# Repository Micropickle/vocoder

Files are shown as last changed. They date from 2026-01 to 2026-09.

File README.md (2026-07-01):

# THE VOCODER

a voice amplifier for use with encumbersome masks such as gas masks

## breif description
the vocoder is a device that allows you to alter your voice to your specifications and allows you to amplify it through speakers and bone transducer speakers and is especially useful in situations where wearing a mask can muffle your voice.

## inspiration
the project was first inspired by a fictonal story/world called degenesis where people called chroniclers disguised their voices using vocoders, long tubes went down their throats to gather their voice and was fed into the 'vocoder' which then was distorted and was amplifiable. along with that i own masks and gasmasks that make it hard to communicate with others so the device is meant to gather your voice via a mic or throat mic and output it via speakers or bone transducer speakers placed on the mask itself which is very useful for hobbies such as airsofting or cosplaying. the device also has professional use cases such as when having to wear heavy clothing and gasmasks such as PPE, this device will make you clearly audible to others when working

## gallery

CAD designs
`photos/CAD designs/KiCad`

initial prototype photos
`photos/prototype version`

## how to use
1. plug in mic of your choice (the standard is the audio jack port found in phones, but the board can be modified for different ports) and wire in an external speaker that meets the specifications of the amplifier chip
2. compile the project on Platformio and flash to the board (this is necessary as in the future i will implement configurations for BLE and initial settings for audio modification such as amplification, distortion, pitch changing, etc.)
3. wire in audio output of your choosing

## bill of materials

`hardware/production/bom.csv`

## initial prototype
it started off as a proof of concept through a prototype board using a simple XIAO esp32 c3 to test the idea and the limitations, this taught me alot digital audio, sound systems and BLE as all three are very necessary for this project
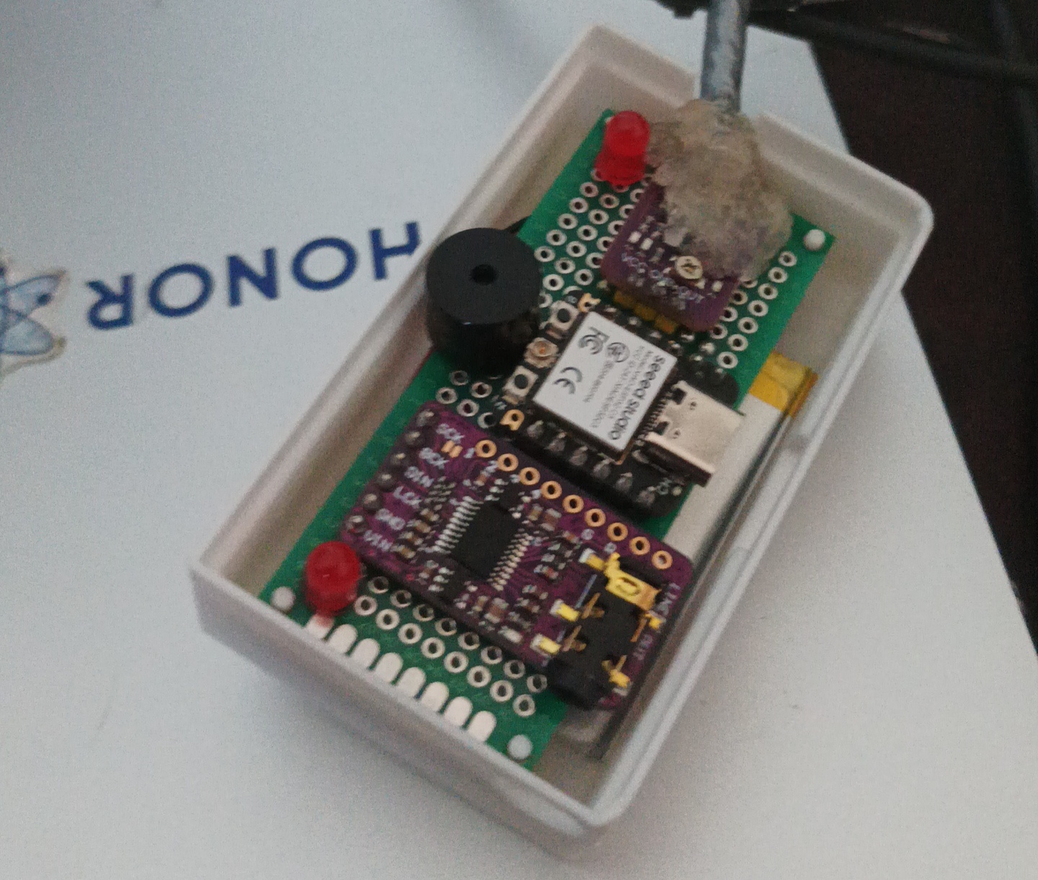
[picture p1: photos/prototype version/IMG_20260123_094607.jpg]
prototype board


the issue was everything was powered by the 3v3 pin on the esp, i had to rely on an external amplifier (and external power supply) to make it work, furthermore the esp's clock speed was too slow and brought about glitches in the audio output. 

## description
the circuit board went through many design stages primarily due to three things, errors, expense and having to include extra components to make the circuit work properly.

the main parts of the circuit are as followed
* the esp32-s3 board was chosen for its high clockspeed, familiarity and extensive functionality, the esp32-s3 WROOM board had included wifi, bluetooth, BLE and usb pins reducing external circuits needed and opening up options in terms of customisation
* the ADAU1761 is a codec that includes a ADC, DAC and built in processor to make changes to the incoming and outcoming audio, this was chosen due to its specialty in audio processing which will reduce the processing power from the esp32 and its ease of programming due to the manufacturers having dedicated graphical software for the chip, the only problem is custom drivers need to be written for the esp32 to upload the code for the ADAU1761
* the MAX98357A was chosen due to its bilt in i2s interfacw which is compatable with the esp32 and the adau1761 as both can be interfaced with the i2s bus, an amplifier was included so that the audio output can be directed to a speaker or bone transucer without an external amplifier or power supply

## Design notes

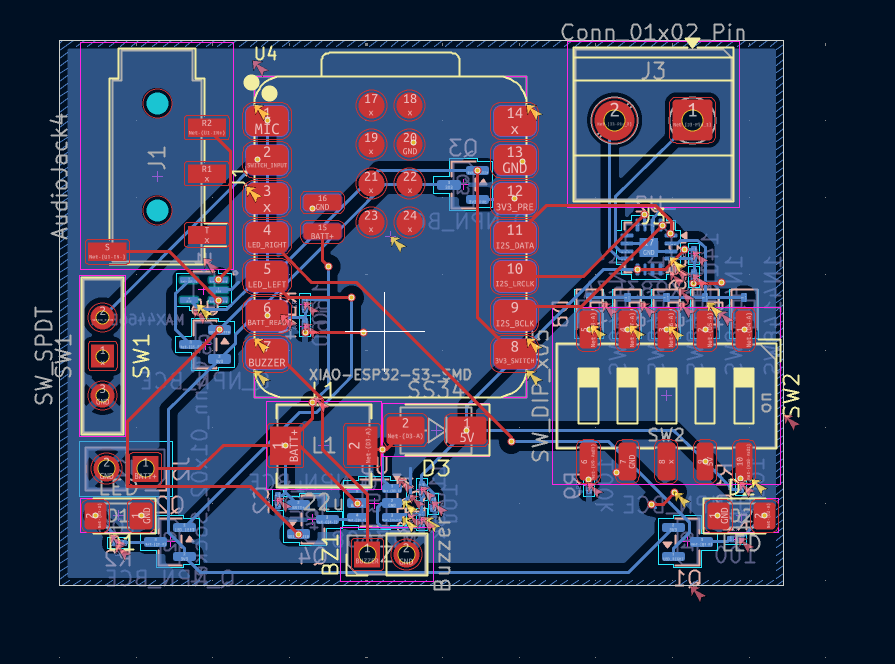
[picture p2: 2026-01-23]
photos/CAD designs/KiCad/Screenshot from 2026-01-22 20-45-09.png

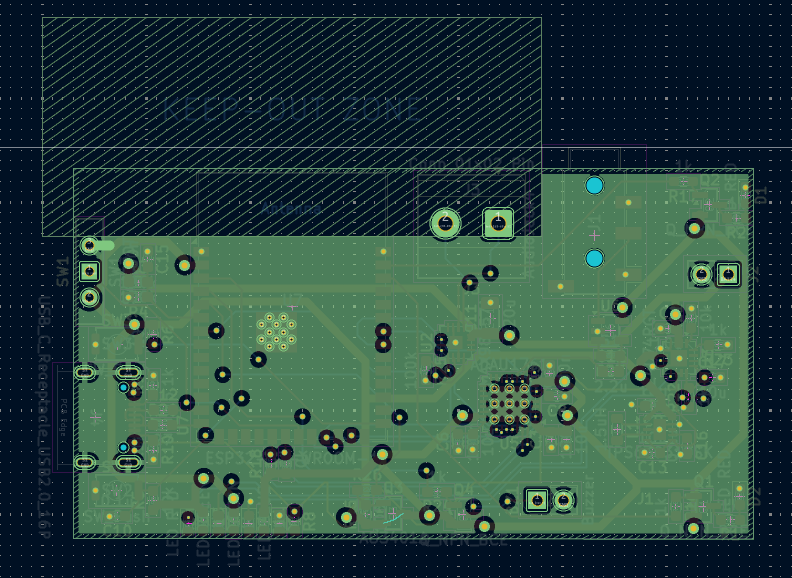
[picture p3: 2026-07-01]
photos/CAD designs/KiCad/Screenshot from 2026-07-01 14-13-31.png

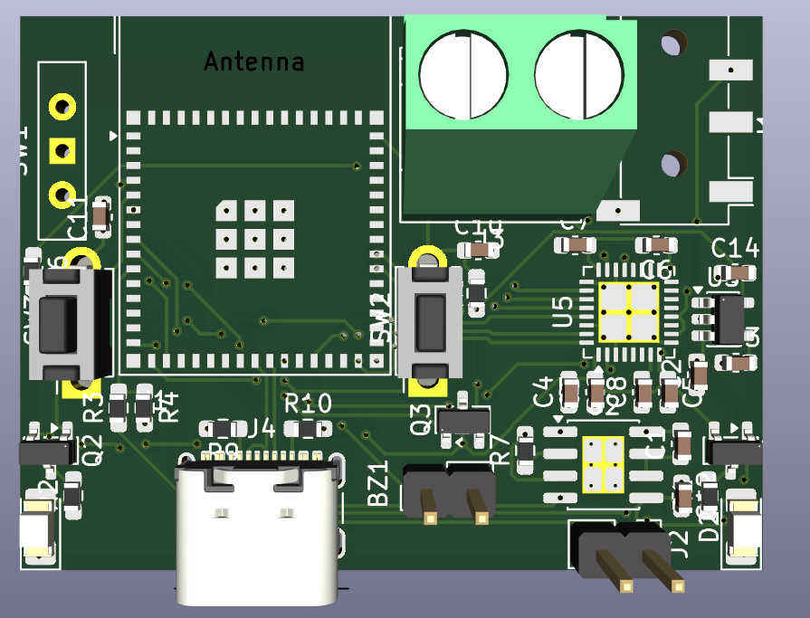
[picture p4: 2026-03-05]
photos/CAD designs/KiCad/Screenshot from 2026-03-05 19-23-45.png

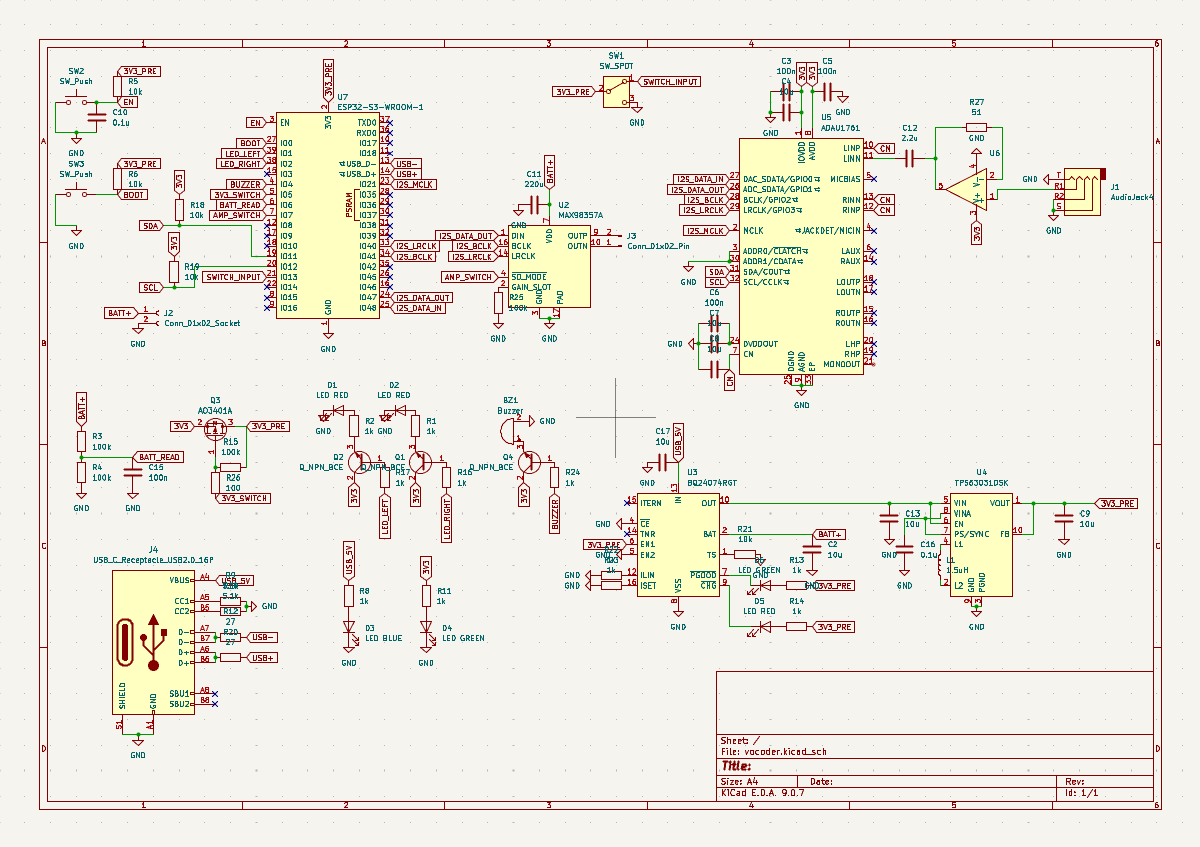
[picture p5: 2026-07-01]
photos/CAD designs/KiCad/Screenshot from 2026-07-01 14-12-51.png

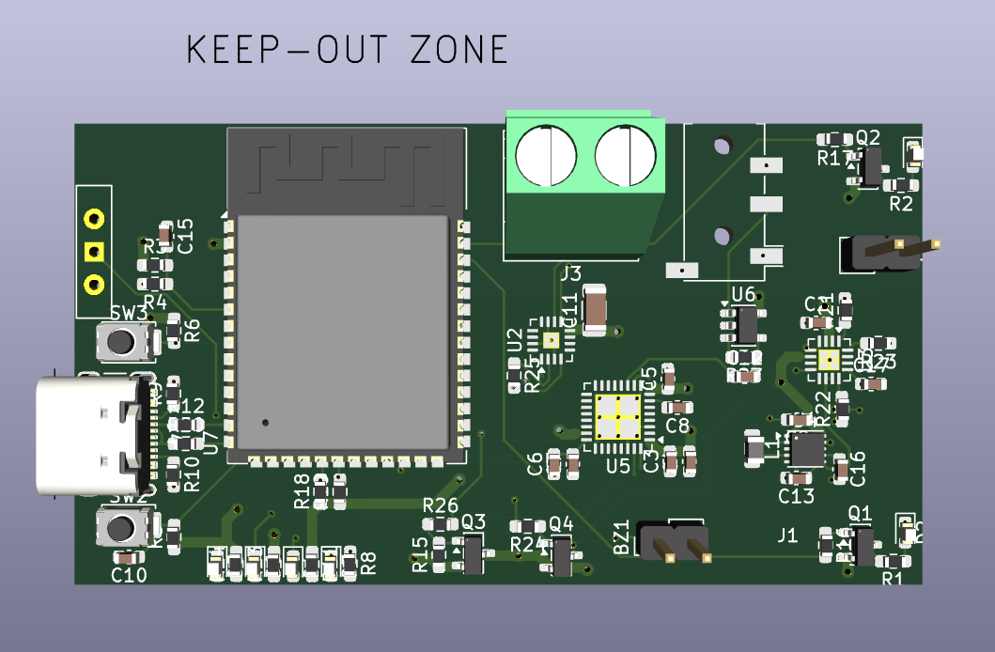
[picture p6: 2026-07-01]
photos/CAD designs/KiCad/Screenshot from 2026-07-01 14-14-14.png

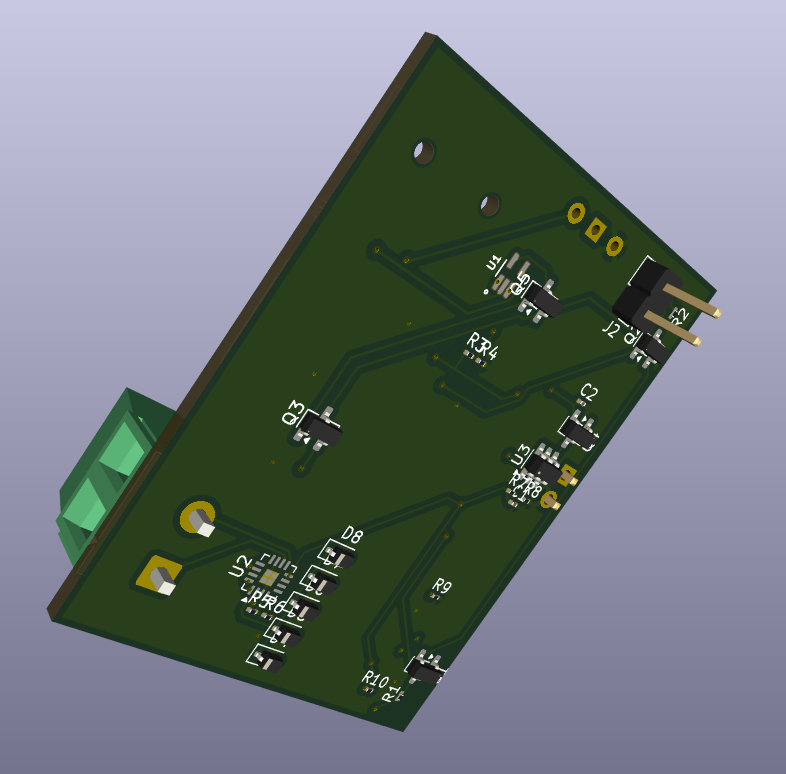
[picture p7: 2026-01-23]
photos/CAD designs/KiCad/Screenshot from 2026-01-22 20-46-21.png

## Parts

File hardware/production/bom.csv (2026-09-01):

Designator | Footprint | Quantity | Value | LCSC Part #
C1, C2, C6, C8 | 0603 | 4 | 1u
C10 | 0603 | 1 | 0.1u
C4, C7 | 0805 | 2 | 10u
J1 | Untitled | 1 | Micro_SD_Card_Det1
J4 | USB_C_Receptacle_GCT_USB4105-xx-A_16P_TopMnt_Horizontal | 1 | USB_C_Receptacle_USB2.0_16P
J5 | PinHeader_1x06_P2.54mm_Vertical | 1 | Conn_02x03_Top_Bottom
LS1 | PinHeader_1x02_P2.54mm_Vertical | 1 | Speaker
R1, R11, R13, R14, R16, R17, R21, R5, R6, R7, R8 | 0603 | 11 | 10k
R10, R9 | 0603 | 2 | 5.1k
R12, R20 | 0603 | 2 | 27
R15 | 0603 | 1 | 100k
SW1 | SW_Tactile_SPST_Angled_PTS645Vx58-2LFS | 1 | SW_Push
SW2, SW3 | SW_SPST_TS-1088-xR020 | 2 | SW_Push
SW4 | RotaryEncoder_Bourns_Horizontal_PEC12R-2x17F-Sxxxx | 1 | RotaryEncoder_Switch
U2 | SOT-23-5 | 1 | AP2112K-3.3
U3 | TQFN-16-1EP_3x3mm_P0.5mm_EP1.23x1.23mm | 1 | MAX98357A
U7 | ESP32-S3-WROOM-1U | 1 | ESP32-S3-WROOM-1

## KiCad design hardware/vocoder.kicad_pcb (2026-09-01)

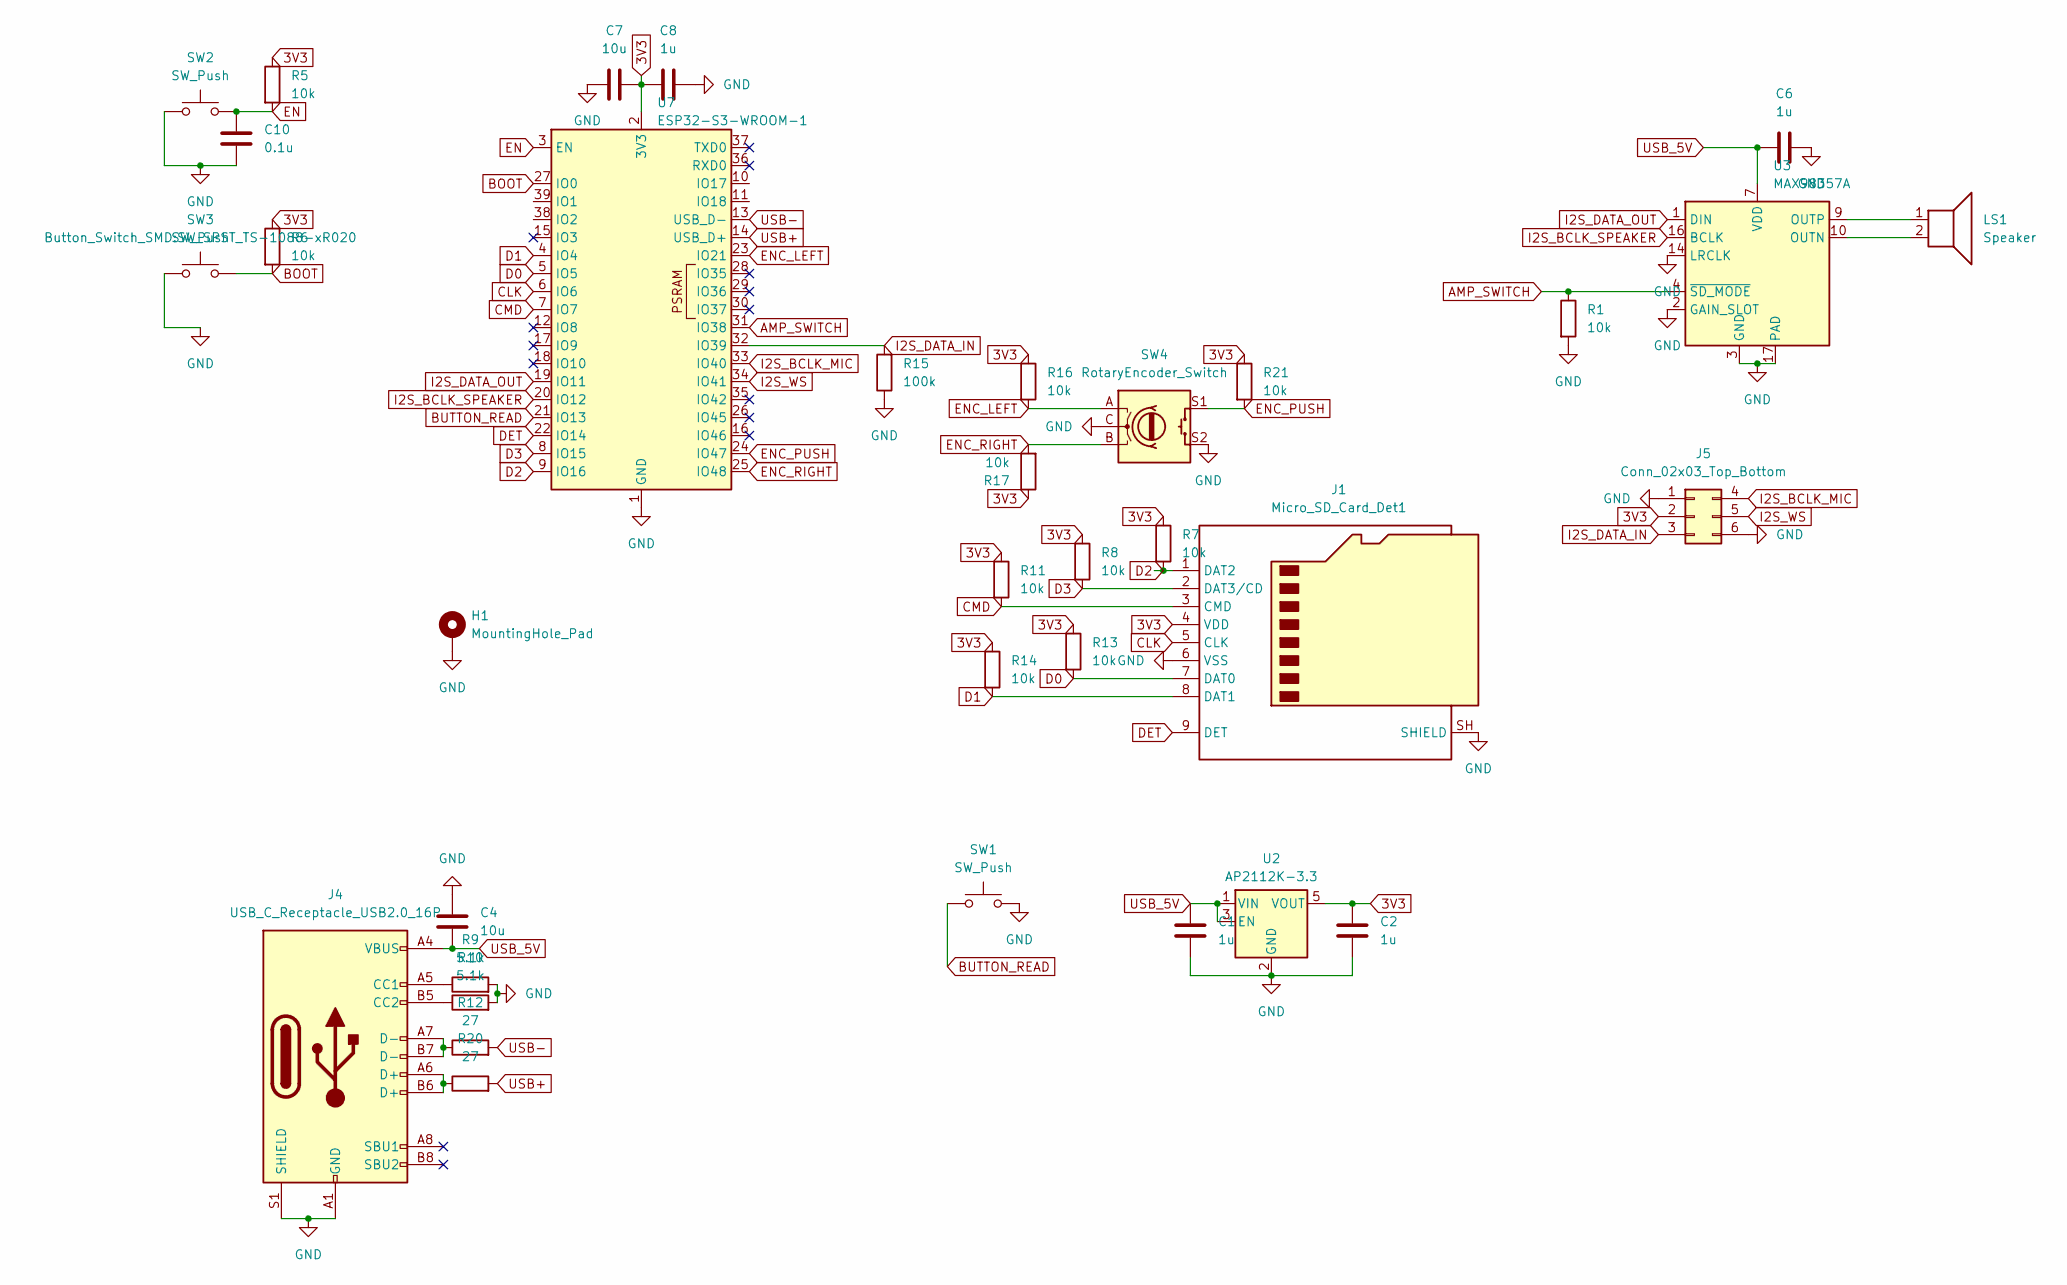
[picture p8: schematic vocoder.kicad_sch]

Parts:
C1, C2, C6, C8: 1u; C_0603_1608Metric
C4, C7: 10u; C_0805_2012Metric
C10: 0.1u; C_0603_1608Metric
H1: MountingHole_Pad; MountingHole_3.2mm_M3_DIN965_Pad
J1: Micro_SD_Card_Det1; Untitled
J4: USB_C_Receptacle_USB2.0_16P; USB_C_Receptacle_GCT_USB4105-xx-A_16P_TopMnt_Horizontal
J5: Conn_02x03_Top_Bottom; PinHeader_1x06_P2.54mm_Vertical
LS1: Speaker; PinHeader_1x02_P2.54mm_Vertical
R1, R5, R6, R7, R8, R11, R13, R14, R16, R17, R21: 10k; R_0603_1608Metric_Pad0.98x0.95mm_HandSolder
R9, R10: 5.1k; R_0603_1608Metric_Pad0.98x0.95mm_HandSolder
R12, R20: 27; R_0603_1608Metric_Pad0.98x0.95mm_HandSolder
R15: 100k; R_0603_1608Metric_Pad0.98x0.95mm_HandSolder
SW1: SW_Push; SW_Tactile_SPST_Angled_PTS645Vx58-2LFS
SW2, SW3: SW_Push; SW_SPST_TS-1088-xR020
SW4: RotaryEncoder_Switch; RotaryEncoder_Bourns_Horizontal_PEC12R-2x17F-Sxxxx
U2: AP2112K-3.3; SOT-23-5
U3: MAX98357A; TQFN-16-1EP_3x3mm_P0.5mm_EP1.23x1.23mm
U7: ESP32-S3-WROOM-1; ESP32-S3-WROOM-1U

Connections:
3V3: C2.1, C7.2, C8.1, J1.4 (VDD), J5.2, R5.1, R6.1, R7.1, R8.1, R11.1, R13.1, R14.1, R16.1, R17.1, R21.1, U2.5 (VOUT), U7.2 (3V3)
AMP_SWITCH: R1.1, U3.4 (~SD_MODE), U7.31 (IO38)
BOOT: R6.2, SW3.2, U7.27 (IO0)
BUTTON_READ: SW1.1, U7.21 (IO13)
CLK: J1.5 (CLK), U7.6 (IO6)
CMD: J1.3 (CMD), R11.2, U7.7 (IO7)
D0: J1.7 (DAT0), R13.2, U7.5 (IO5)
D1: J1.8 (DAT1), R14.2, U7.4 (IO4)
D2: J1.1 (DAT2), R7.2, U7.9 (IO16)
D3: J1.2 (DAT3/CD), R8.2, U7.8 (IO15)
DET: J1.9 (DET), U7.22 (IO14)
EN: C10.1, R5.2, SW2.2, U7.3 (EN)
ENC_LEFT: R16.2, SW4.A, U7.23 (IO21)
ENC_PUSH: R21.2, SW4.S1, U7.24 (IO47)
ENC_RIGHT: R17.2, SW4.B, U7.25 (IO48)
GND: C1.2, C2.2, C4.2, C6.2, C7.1, C8.2, C10.2, H1.1 (1_1), J1.6 (VSS), J1.SH (SHIELD), J4.A1 (GND), J4.A12 (GND), J4.B1 (GND), J4.B12 (GND), J4.S1 (SHIELD), J5.1, J5.6, R1.2, R9.2, R10.2, R15.1, SW1.2, SW2.1, SW3.1, SW4.C, SW4.S2, U2.2 (GND), U3.2 (GAIN_SLOT), U3.3 (GND), U3.11 (GND), U3.14 (LRCLK), U3.15 (GND), U3.17 (PAD), U7.1 (GND), U7.40 (GND), U7.41 (GND)
I2S_BCLK_MIC: J5.4, U7.33 (IO40)
I2S_BCLK_SPEAKER: U3.16 (BCLK), U7.20 (IO12)
I2S_DATA_IN: J5.3, R15.2, U7.32 (IO39)
I2S_DATA_OUT: U3.1 (DIN), U7.19 (IO11)
I2S_WS: J5.5, U7.34 (IO41)
unnamed: J4.A5 (CC1), R9.1
unnamed: J4.B5 (CC2), R10.1
unnamed: J4.A6 (D+), J4.B6 (D+), R20.1
unnamed: J4.A7 (D-), J4.B7 (D-), R12.1
unnamed: LS1.2, U3.10 (OUTN)
unnamed: LS1.1, U3.9 (OUTP)
USB+: R20.2, U7.14 (USB_D+)
USB-: R12.2, U7.13 (USB_D-)
USB_5V: C1.1, C4.1, C6.1, J4.A4 (VBUS), J4.A9 (VBUS), J4.B4 (VBUS), J4.B9 (VBUS), U2.1 (VIN), U2.3 (EN), U3.7 (VDD), U3.8 (VDD)

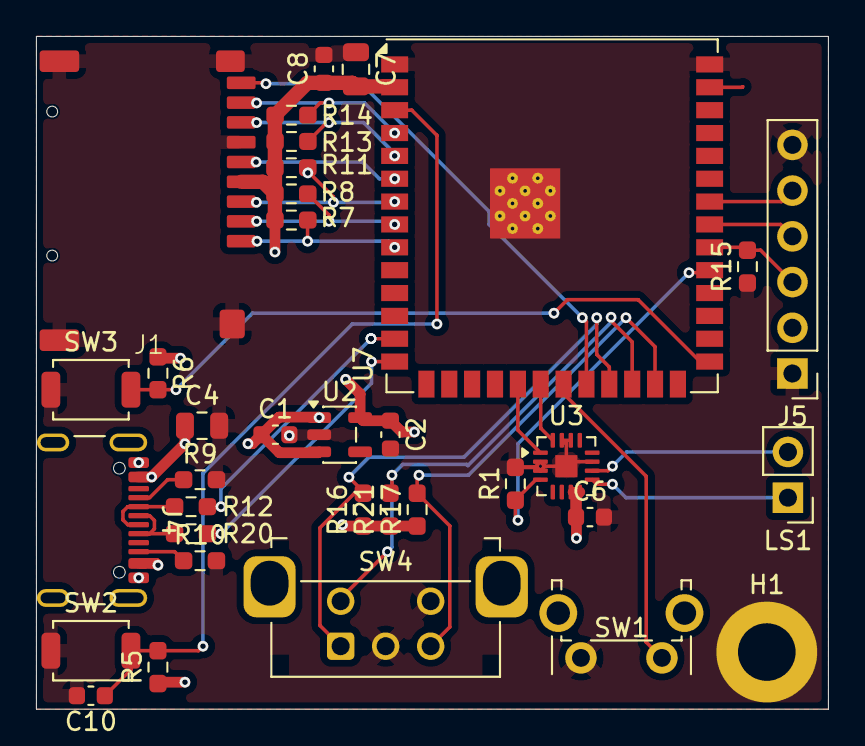
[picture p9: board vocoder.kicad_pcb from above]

Board: 4 copper layers, 44.0 x 37.4 mm, 35 parts (0 on the bottom side), 30 nets.

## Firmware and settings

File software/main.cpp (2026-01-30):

#include <Arduino.h>
#include <driver/i2s.h>
#include <esp_timer.h>
#include <string.h>
#include <math.h>


// ============================================================================
// PIN CONFIGURATION
// ============================================================================

#define PIN_I2S_BCLK  8
#define PIN_I2S_WORD  10
#define PIN_I2S_DATA  9
#define PIN_I2S_MCLK  7

#define PIN_ADC_MIC   4

#define PIN_LED       3
#define PIN_BUZZER    2

// ============================================================================
// AUDIO CONFIGURATION
// ============================================================================

#define SAMPLE_RATE   16000 //8000 gives telephone quality, 16000 offers decent voice transmittion, 44100 offers cd quality music, 48000 gives overall good quality used for music, DVD playing and video
#define BIT_DEPTH     8 // 8 bit audio gives choppy sound, 16 bit offers audio quality compared to a smartphone
#define ADC_BIAS    2230
#define NOISE_THRESHOLD 30
#define BUFFER_COUNT 2
#define BUFFER_SIZE  512 //latency increases with buffer size, 64 offers almost instant playback, 512 offers half a second delay (all dependant on buffer count)

int16_t input_buffer[BUFFER_SIZE];
int16_t output_buffer[BUFFER_SIZE];
int buffer_pos = 0;
// if CPU cannot keep up then audible pops can be heard, if the case then increase buffer size

// an increase in buffer size decreases the frequency of CPU interruptions but increases latency and uses more memory
// an increase in buffer count decreases glitching but also uses more memory

// large buffer lengths but little buffer count = high latency
// low buffer length but many buffers = high interrupt load

// ============================================================================
// AUDIO FUNCTIONS
// ============================================================================

void setup_adc() {
  analogSetPinAttenuation(PIN_ADC_MIC, ADC_11db);
  analogReadResolution(BIT_DEPTH);
}

void input_sample() {
  uint16_t adc_val = analogRead(PIN_ADC_MIC);

  int16_t centred_sample = (int16_t)(adc_val - ADC_BIAS);
  if (abs(centred_sample) < NOISE_THRESHOLD) {
    centred_sample = 0;
  }
  
  input_buffer[buffer_pos] = centred_sample * 64;
}

void process_sample() {
  int16_t processed_sample = input_buffer[buffer_pos];
  // voice changer effects here
  output_buffer[buffer_pos] = processed_sample;
  buffer_pos++;
}

void output_sample() {
  if (buffer_pos >= BUFFER_SIZE) {
    size_t bytes_written = 0;
    i2s_write(I2S_NUM_0, output_buffer, BUFFER_SIZE * sizeof(int16_t), &bytes_written, portMAX_DELAY);
    buffer_pos = 0;
  }
}
void accurate_delays() {
  static uint32_t last_time = 0;
  uint32_t current_time = esp_timer_get_time();
  uint32_t sample_period_us = 1000000 / SAMPLE_RATE;

  while ((current_time - last_time) < sample_period_us) {
    current_time = esp_timer_get_time();
    ets_delay_us(1);
  }
  last_time = current_time;
}

void audio_handler(void* parameter) {
  while (1) {
    input_sample();
    process_sample();
    output_sample();
    accurate_delays();
  }
}

void audio_init() {
  setup_adc();

  xTaskCreate(
    audio_handler,
    "audio_handler",
    1000,
    NULL,
    3,
    NULL
  );
}

// ============================================================================
// I2S SETUP
// ============================================================================

void setup_i2s() {
  i2s_config_t i2s_config = {
    .mode = (i2s_mode_t)(I2S_MODE_MASTER | I2S_MODE_TX),
    .sample_rate = SAMPLE_RATE,
    .bits_per_sample = I2S_BITS_PER_SAMPLE_16BIT,
    .channel_format = I2S_CHANNEL_FMT_ALL_RIGHT,
    .communication_format = I2S_COMM_FORMAT_STAND_I2S,
    .intr_alloc_flags = ESP_INTR_FLAG_LEVEL1,
    .dma_buf_count = BUFFER_COUNT,
    .dma_buf_len = BUFFER_SIZE,
    .use_apll = true,
    .tx_desc_auto_clear = true,
    .fixed_mclk = 0
  };
  i2s_pin_config_t pin_config = {
    .mck_io_num = PIN_I2S_MCLK,
    .bck_io_num = PIN_I2S_BCLK,
    .ws_io_num = PIN_I2S_WORD,
    .data_out_num = PIN_I2S_DATA,
    .data_in_num = I2S_PIN_NO_CHANGE
  };
  i2s_driver_install(I2S_NUM_0, &i2s_config, 0, NULL);
  i2s_set_pin(I2S_NUM_0, &pin_config);
  i2s_set_clk(I2S_NUM_0, SAMPLE_RATE, I2S_BITS_PER_SAMPLE_16BIT, I2S_CHANNEL_MONO);
}

// ============================================================================
// EXTRAS
// ============================================================================

uint8_t default_pitch = 255;

void buzzer_beep(size_t amount = 1, uint32_t onTime = 100, uint32_t offTime = 100, uint8_t pitch = default_pitch) {
  for (int i = 0; i < amount; i++) {
    analogWrite(PIN_BUZZER, pitch);
    delay(onTime);
    analogWrite(PIN_BUZZER, 0);
    delay(offTime);
  }
  return;
}

int default_freq = 5000;

void buzzer_beep_freq(size_t amount = 1, uint32_t onTime = 100, uint32_t offTime = 100, int freq = default_freq) {
  for (int i = 0; i < amount; i++) {
    tone(PIN_BUZZER, freq, onTime);
    delay(offTime);
  }
  return;
}

uint8_t default_brightness = 255;

void led_flicker(size_t amount = 1, uint32_t onTime = 50, uint32_t offTime = 300, uint8_t brightness = default_brightness) {
  for (int i = 0; i < amount; i++) {
    analogWrite(PIN_LED, brightness);
    delay(onTime);
    analogWrite(PIN_LED, 0);
    delay(offTime);
  }
  return;
}

void led_buzzer(size_t amount = 1, uint32_t onTime = 50, uint32_t offTime = 300, int freq = default_freq, uint8_t brightness = default_brightness) {
  for (int i = 0; i < amount; i++) {
    analogWrite(PIN_LED, brightness);
    tone(PIN_BUZZER, freq, onTime);
    delay(onTime);
    analogWrite(PIN_LED, 0);
    delay(offTime);
  }
  return;
}

// ============================================================================
// BLUETOOTH COMMANDS
// ============================================================================

//heirarchy:    profile(server)->service->characteristic->properties+value+descriptor

#include <BLEDevice.h>
#include <BLEUtils.h>
#include <BLEServer.h>
#include <BLEUUID.h>
#include <BLESecurity.h>

#define SERVICE_TEST_UUID        "c4f1f458-f41b-45c9-8636-7e098e715259"
#define CHARACTERISTIC_TEST_UUID "6829258f-513c-47c2-b6ac-328ce39ddd94"

BLEServer *btServer;
BLECharacteristic *btCharacteristics;
BLESecurity *btSecurity;

#define BTNAME "vocoder"

#define BT_ADV_POWER ESP_PWR_LVL_N12  // -12dBm (low power)
#define BT_CONN_POWER ESP_PWR_LVL_P9  // +9dBm (high power when connected)


bool deviceConnected = false;
bool oldDeviceConnected = false;
bool advertising = false;
std::string input;

class MyServerCallbacks : public BLEServerCallbacks {
  void onConnect(BLEServer *pServer) {
    led_buzzer(2, 50, 100, 5000);
    deviceConnected = true;
    advertising = false;
  };

  void onDisconnect(BLEServer *pServer) {
    led_buzzer(1, 200, 0, 5000);
    if (!advertising) {
      btServer->startAdvertising();
      deviceConnected = false;
      advertising = true;
    }
  }
};

class MyCharacteristicCallbacks : public BLECharacteristicCallbacks {
  void onWrite(BLECharacteristic* pCharacteristic) {
    input = pCharacteristic->getValue();
    Serial.print("message: "); Serial.print(input.c_str()); Serial.println();
  }
  void onRead(BLECharacteristic* pChar) {
    Serial.println("characteristic read");
  }
};

void bt_init() {
  BLEDevice::init(BTNAME);
  btServer = BLEDevice::createServer();
  btServer->setCallbacks(new MyServerCallbacks);


  BLEService *btService = btServer->createService(SERVICE_TEST_UUID);

  btCharacteristics = btService->createCharacteristic(
                      CHARACTERISTIC_TEST_UUID,
                      BLECharacteristic::PROPERTY_READ   |
                      BLECharacteristic::PROPERTY_WRITE  |
                      BLECharacteristic::PROPERTY_NOTIFY
                    );
  btCharacteristics->setCallbacks(new MyCharacteristicCallbacks);

  btCharacteristics->setValue("testing");

  btService->start();


  BLEAdvertising *btAdvertising = btServer->getAdvertising();
  btAdvertising->addServiceUUID(SERVICE_TEST_UUID);
  btAdvertising->setScanResponse(true);
  btAdvertising->setMinInterval(0x0064);  // 100ms in 0.625ms units
  btAdvertising->setMaxInterval(0x00C8);  // 200ms in 0.625ms units
  if (!advertising) {
    btServer->startAdvertising();
    advertising = true;
  }

  return;
}

// ============================================================================
// SETUP
// ============================================================================

void setup() {
  Serial.begin(115200);
  bt_init();
  analogReadResolution(12);
  analogSetAttenuation(ADC_11db);
  setup_i2s();
  audio_init();
}

// ============================================================================
// MAIN LOOP
// ============================================================================


void loop() {
  vTaskDelay(10 / portTICK_PERIOD_MS);
}

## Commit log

2026-01-22 hardware complete
    [bom.csv, designators.csv, positions.csv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]
2026-01-27 Revise README with project details and BOM
    Updated README.md to include additional information about the vocoder project, including a general buying section for common components and a more detailed bill of materials.
2026-01-27 changed sizes to JLCPCB acceptable sizes
    [bom.csv, positions.csv, vocoder.kicad_pcb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]
2026-02-12 fixed component placement
    [vocoder.kicad_pcb]
2026-02-12 placed bom file in root diretory
    [bom.csv]
2026-02-13 fixed grounding pad not attatched to ground plane
    [vocoder.kicad_pcb]
2026-03-05 complete redesign of board and circuit, smaller and more powerful
    [bom.csv, designators.csv, positions.csv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]
2026-03-05 fixed minor error
    [vocoder.kicad_pcb, vocoder.kicad_sch]
2026-03-05 bom file didnt feel like updating
2026-03-06 trying to fix bom
2026-03-09 fixing production files
    [bom.csv, designators.csv, positions.csv]
2026-03-09 changed buttons to smaller SMT ones
    [bom.csv, positions.csv, vocoder.kicad_pcb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]
2026-03-09 added BOM
2026-04-20 added debug led's
    [vocoder.kicad_pcb, vocoder.kicad_sch]
2026-04-20 file cleanup
    [bom.csv, positions.csv]
2026-06-26 working circuit without amplifier
    [bom.csv, designators.csv, positions.csv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]
2026-07-01 replaced esp32-s3 mini with esp32-s3-wroom, added needed op amp and amp
    [bom.csv, designators.csv, positions.csv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]
2026-07-01 updated README for BOM file, gallery and description
    the README file was updated so that both BOM file and gallery paths are included instead of static text and images allowing for automatic updating when new commit and changes happen
    the description was updated to better describe the purpose of each main IC
2026-08-31 semi working before removing battery and adding necessary changes
    [bom.csv, designators.csv, positions.csv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]
2026-09-01 reduced board size, removed BMS, will be powered externally only, fixed I2S wiring
    [bom.csv, designators.csv, positions.csv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]
